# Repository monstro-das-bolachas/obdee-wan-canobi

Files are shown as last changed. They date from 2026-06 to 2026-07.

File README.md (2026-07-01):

# OBDee-Wan CANobi

> Open-hardware automotive bus interface for CAN FD, classic CAN, LIN, and K-line exploration.

OBDee-Wan CANobi is a Teensy 4.1 based vehicle-network tool for hackers, makers, reverse engineers, EV converters, and curious learners who want hardware they can inspect and understand.

It is designed as a practical bridge between a laptop and a vehicle or bench module: powerful enough for real CAN FD/LIN/K-line experiments, but documented as a teaching project rather than a black box.






## At a glance

| Area | Current R11 target |
| --- | --- |
| Host | Teensy 4.1 |
| CAN FD | 2 external CAN FD controller paths |
| Transceivers | Dual CAN FD transceivers |
| Other buses | LIN / K-line support path |
| Vehicle connection | OBD pigtail-friendly wiring, not a direct-plug dongle |
| Configuration | DIP-switch selectable routing options |
| CAD | KiCad hardware source and generated fabrication packages |
| Readiness | Bare-PCB prototype candidate for bench bring-up |

## What you can use it for

- CAN FD experimentation and learning
- Classic CAN diagnostics and reverse engineering
- LIN and K-line bench experiments
- EV conversion support tooling
- Custom diagnostic interface development
- Teaching automotive networks with inspectable hardware
- Bench testing ECUs, modules, sensors, and harness fragments

## Current status: R11 prototype manufacturing candidate

R11 may be ordered as a small bare-PCB prototype batch for bench bring-up.

It is not approved for direct vehicle testing yet.

### Active release package

`revisions/00_WORK_R11_TRUE_DUAL_CANFD/release/R11_PROTOTYPE_MANUFACTURING_CANDIDATE_20260630/`

### Manufacturer upload ZIP

`revisions/00_WORK_R11_TRUE_DUAL_CANFD/release/R11_PROTOTYPE_MANUFACTURING_CANDIDATE_20260630/package/JLCPCB_PCBWAY_UPLOAD_R11_MINIMAL_GERBERS_ONLY_20260630.zip`

SHA256:

`434dedf475bb3443f1ffa6384541426fcef9cf96a792c1744b9c1bb7ff68faa8`

### Verification summary

| Check | Result |
| --- | --- |
| KiCad CLI PCB DRC | 0 violations |
| KiCad schematic catalog ERC | 0 errors / 0 warnings |
| Footprint errors | 0 |
| Known residual | 1 GND zone-to-zone report at 1.0000 mm / 1.0000 mm |
| Gerber/drill export | Successful |
| GND continuity | Visually confirmed in KiCad after refill/highlight |
| BOM/CPL | PCB-derived BOM, grouped BOM, JLCPCB draft BOM/CPL included |
| Vehicle-use approval | Not yet; bench validation required first |

The remaining GND item is a reviewed KiCad zone-report artifact for prototype PCB ordering. It is not a blanket safety approval for vehicle connection.

## Safety first

Vehicle electrical systems can damage tools, modules, or the car if connected incorrectly. Treat every first assembly as experimental hardware.

Before connecting to a vehicle:

1. Inspect the bare PCB.
2. Check for rail shorts with a multimeter.
3. Assemble and test the power section first.
4. Power up from a current-limited bench supply.
5. Verify OBD/pigtail pin mapping manually.
6. Confirm DIP-switch defaults and intended routing.
7. Test CAN/LIN/K behavior on bench modules first.
8. Use fusing and current limiting for any later vehicle test.

## Repository map

| Path | Purpose |
| --- | --- |
| `README_START_HERE.txt` | Short navigation and safety guide |
| `CURRENT_STATUS.md` | Current revision status, ordering notes, and verification summary |
| `revisions/00_WORK_R11_TRUE_DUAL_CANFD/` | Active R11 prototype candidate source and release package |
| `revisions/00_WORK_R11_TRUE_DUAL_CANFD/docs/R11_BOM_FROM_PCB.md` | PCB-derived R11 BOM and procurement-review starting point |
| `revisions/00_WORK_R11_TRUE_DUAL_CANFD/docs/R11_PCB_DERIVED_NETLIST.md` | Pad/net evidence exported from the active PCB |
| `LOCAL_ARCHIVE_POINTERS.md` | Local-only pointers to R2-R10 evolution archives on this machine |
| GitHub releases / tags | Previous R10 and R9 snapshots; not duplicated in the latest working tree |
| `LICENSE` | Main hardware license: CERN-OHL-P-2.0 |
| `LICENSES/` | Full license texts and license split documentation |

## Recommended first order

For the first prototype batch, use conservative bare-board settings:

| Option | Recommendation |
| --- | --- |
| Quantity | 5 or smallest economical batch |
| Layers | 2 |
| Material | FR-4 |
| Thickness | 1.6 mm |
| Copper | 1 oz |
| Surface finish | Standard low-cost prototype finish is acceptable |
| Electrical test | Yes |
| Assembly | No; hand-assemble and validate first |

## Naming note

The project name is a small joke:

OBDee-Wan CANobi: an OBD/CAN interface that helps you feel disturbances in the bus.

## License

This project is open source and open hardware.

| Content | License |
| --- | --- |
| Hardware design files, KiCad sources, PCB/manufacturing files | CERN-OHL-P-2.0 |
| Firmware, scripts, and software | MIT |
| Documentation | CC-BY-4.0 |

You are free to study, modify, build, remix, and share this project. Attribution is required where applicable: please credit the original project and author when reusing or publishing derivative work.

See `LICENSES/README.md` for the full license split and SPDX identifiers.

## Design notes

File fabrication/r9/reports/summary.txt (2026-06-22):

R9 FAB_READY verification run: r9_fab_ready_20260622T095215Z
Board: /home/kali/teensy-41-can-lin-pcb/teensy-41-dual-canfd-lin-r9-final-candidate.kicad_pcb

=== KiCad version ===
10.0.3

=== PCB DRC ===
Found 0 violations
Found 0 unconnected items
Saved DRC Report to reports/r9_fab_ready_20260622T095215Z/drc.rpt
** Drc report for teensy-41-dual-canfd-lin-r9-final-candidate.kicad_pcb **
** Created on 2026-06-22T05:52:18 **
** Report includes: Errors, Warnings **

** Found 0 DRC violations **

** Found 0 unconnected pads **

** Found 0 Footprint errors **

** Ignored checks **
    - Footprint has no courtyard defined
    - Track endpoint not centered on via
    - Tuning profile track geometries
    - Footprint doesn't match symbol's footprint filters
    - Footprint component type doesn't match footprint pads

** End of Report **

=== SVG smoke export ===
Plotted to 'previews/r9_fab_ready_20260622T095215Z/teensy-41-dual-canfd-lin-r9-final-candidate-F_Cu.svg'.
Plotted to 'previews/r9_fab_ready_20260622T095215Z/teensy-41-dual-canfd-lin-r9-final-candidate-B_Cu.svg'.
Plotted to 'previews/r9_fab_ready_20260622T095215Z/teensy-41-dual-canfd-lin-r9-final-candidate-F_Silkscreen.svg'.
Plotted to 'previews/r9_fab_ready_20260622T095215Z/teensy-41-dual-canfd-lin-r9-final-candidate-B_Silkscreen.svg'.
Plotted to 'previews/r9_fab_ready_20260622T095215Z/teensy-41-dual-canfd-lin-r9-final-candidate-F_Fab.svg'.
Plotted to 'previews/r9_fab_ready_20260622T095215Z/teensy-41-dual-canfd-lin-r9-final-candidate-B_Fab.svg'.
Plotted to 'previews/r9_fab_ready_20260622T095215Z/teensy-41-dual-canfd-lin-r9-final-candidate-Edge_Cuts.svg'.
Done.

=== Gerber export ===
Plotted to 'gerbers/r9_fab_ready_20260622T095215Z/teensy-41-dual-canfd-lin-r9-final-candidate-F_Cu.gtl'.
Plotted to 'gerbers/r9_fab_ready_20260622T095215Z/teensy-41-dual-canfd-lin-r9-final-candidate-B_Cu.gbl'.
Plotted to 'gerbers/r9_fab_ready_20260622T095215Z/teensy-41-dual-canfd-lin-r9-final-candidate-F_Silkscreen.gto'.
Plotted to 'gerbers/r9_fab_ready_20260622T095215Z/teensy-41-dual-canfd-lin-r9-final-candidate-B_Silkscreen.gbo'.
Plotted to 'gerbers/r9_fab_ready_20260622T095215Z/teensy-41-dual-canfd-lin-r9-final-candidate-F_Mask.gts'.
Plotted to 'gerbers/r9_fab_ready_20260622T095215Z/teensy-41-dual-canfd-lin-r9-final-candidate-B_Mask.gbs'.
Plotted to 'gerbers/r9_fab_ready_20260622T095215Z/teensy-41-dual-canfd-lin-r9-final-candidate-Edge_Cuts.gm1'.

=== Drill export ===
Created file 'gerbers/r9_fab_ready_20260622T095215Z/teensy-41-dual-canfd-lin-r9-final-candidate.drl'
Done.

=== Gerber files ===
teensy-41-dual-canfd-lin-r9-final-candidate-B_Cu.gbl
teensy-41-dual-canfd-lin-r9-final-candidate-B_Mask.gbs
teensy-41-dual-canfd-lin-r9-final-candidate-B_Silkscreen.gbo
teensy-41-dual-canfd-lin-r9-final-candidate.drl
teensy-41-dual-canfd-lin-r9-final-candidate-Edge_Cuts.gm1
teensy-41-dual-canfd-lin-r9-final-candidate-F_Cu.gtl
teensy-41-dual-canfd-lin-r9-final-candidate-F_Mask.gts
teensy-41-dual-canfd-lin-r9-final-candidate-F_Silkscreen.gto
teensy-41-dual-canfd-lin-r9-final-candidate-job.gbrjob

=== Package status ===
FAB_READY
Package directory: /home/kali/teensy-41-can-lin-pcb/packages/r9_fab_ready_20260622T095215Z
Package zip: /home/kali/teensy-41-can-lin-pcb/FAB_READY_R9_teensy-41-dual-canfd-lin_20260622T095215Z.zip
f04ae2c23580a58f2644d54cbd61c455111c15dcdaf9954a5cab5cf20b73ea5e  FAB_READY_R9_teensy-41-dual-canfd-lin_20260622T095215Z.zip

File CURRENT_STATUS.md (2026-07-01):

# Current project status

Last checked/updated: 2026-06-30

## Executive summary

The active hardware revision is now **R11 true dual CAN FD + LIN/K prototype manufacturing candidate**.

R11 may be ordered as a small bare-PCB prototype batch for bench bring-up. It is **not approved for direct vehicle testing** until assembled boards pass continuity, power, pin-map, and fused OBD bench checks.

## Active R11 files

Active working revision folder:

- `revisions/00_WORK_R11_TRUE_DUAL_CANFD/`

Clean release package folder:

- `revisions/00_WORK_R11_TRUE_DUAL_CANFD/release/R11_PROTOTYPE_MANUFACTURING_CANDIDATE_20260630/`

Active KiCad source:

- `revisions/00_WORK_R11_TRUE_DUAL_CANFD/kicad/teensy-41-true-dual-canfd-lin-r11_JARVIS_ROUTED_CLEAN_V2_GND_STITCH.kicad_pcb`
- `revisions/00_WORK_R11_TRUE_DUAL_CANFD/kicad/teensy-41-true-dual-canfd-lin-r11_JARVIS_ROUTED_CLEAN_V2_GND_STITCH.kicad_pro`

JLCPCB / PCBWay upload ZIP:

- `revisions/00_WORK_R11_TRUE_DUAL_CANFD/release/R11_PROTOTYPE_MANUFACTURING_CANDIDATE_20260630/package/JLCPCB_PCBWAY_UPLOAD_R11_MINIMAL_GERBERS_ONLY_20260630.zip`

Full release ZIP:

- `revisions/00_WORK_R11_TRUE_DUAL_CANFD/release/R11_PROTOTYPE_MANUFACTURING_CANDIDATE_20260630/package/R11_PROTOTYPE_MANUFACTURING_CANDIDATE_20260630_FULL_RELEASE.zip`

## R11 verification

KiCad CLI DRC was run against the active board and the clean release-copy board.

Reports:

- `revisions/00_WORK_R11_TRUE_DUAL_CANFD/release/R11_PROTOTYPE_MANUFACTURING_CANDIDATE_20260630/reports/R11_PROTOTYPE_CANDIDATE_DRC.rpt`
- `revisions/00_WORK_R11_TRUE_DUAL_CANFD/release/R11_PROTOTYPE_MANUFACTURING_CANDIDATE_20260630/reports/R11_PROTOTYPE_CANDIDATE_CLEAN_RELEASE_COPY_DRC.rpt`

Result:

- DRC violations: 0
- Known residual: 1 GND F.Cu/B.Cu zone-to-zone unconnected report at 1.0000 mm / 1.0000 mm
- Footprint errors: 0
- Gerber/drill export: successful
- GND continuity: visually confirmed in KiCad after zone refill/highlight

The residual GND item is treated as a reviewed KiCad zone-report artifact for prototype PCB ordering, not as approval for vehicle use.

## R11 schematic/BOM completion

Added on 2026-07-01 from the active PCB:

- PCB-derived KiCad schematic catalog: `revisions/00_WORK_R11_TRUE_DUAL_CANFD/kicad/teensy-41-true-dual-canfd-lin-r11_JARVIS_ROUTED_CLEAN_V2_GND_STITCH.kicad_sch`
- KiCad ERC on the generated schematic catalog: 0 errors / 0 warnings
- KiCad schematic netlist export: `revisions/00_WORK_R11_TRUE_DUAL_CANFD/docs/R11_PCB_DERIVED_SCHEMATIC_NETLIST.xml`
- BOM: `revisions/00_WORK_R11_TRUE_DUAL_CANFD/docs/R11_BOM_FROM_PCB.md` and `.csv`
- Grouped BOM: `revisions/00_WORK_R11_TRUE_DUAL_CANFD/docs/R11_BOM_GROUPED_FROM_PCB.csv`
- JLCPCB draft BOM/CPL: `R11_JLCPCB_BOM_DRAFT.csv`, `R11_JLCPCB_CPL_DRAFT.csv`
- PCB-derived pad/net table: `R11_PCB_DERIVED_NETLIST.md`, `R11_PAD_NETS_FROM_PCB.csv`

Important limitation: this schematic is a PCB-derived catalog with footprint links and BOM/ERC proof, not yet a hand-reviewed functional wired schematic. The active PCB remains the layout authority; the pad/net table is the electrical evidence for review.

## R11 prototype ordering guidance

Order only a small bare-PCB batch first:

- 2 layers
- FR-4
- 1.6 mm
- 1 oz copper
- 5 pieces or smallest economical batch
- electrical test enabled
- no assembly for first order

Before vehicle testing:

1. Inspect bare PCBs.
2. Check GND continuity and rail shorts with a multimeter.
3. Assemble power section first.
4. Power from a current-limited bench supply.
5. Verify OBD/pigtail pin mapping with a multimeter.
6. Verify DIP switch safe/default positions.
7. Test CAN/LIN/K behavior on bench hardware before a fused OBD vehicle connection.

## Previous revision status

The latest working tree intentionally keeps only the active R11 prototype candidate under `revisions/`.

R10 and R9 remain available through GitHub history/releases/tags, but are no longer duplicated in the latest repository tree:

- R10: `NOT FOR FAB` after external review.
- R9: historical/reference material only; not true dual CAN FD.

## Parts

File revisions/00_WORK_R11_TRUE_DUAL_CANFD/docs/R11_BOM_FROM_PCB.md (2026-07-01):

# R11 BOM from active PCB

Source board: `../kicad/teensy-41-true-dual-canfd-lin-r11_JARVIS_ROUTED_CLEAN_V2_GND_STITCH.kicad_pcb`

Status: PCB-derived draft BOM. Suitable for procurement review, not automated assembly without MPN/LCSC completion.

Footprints/components: 59

| Qty | Designators | Value | Footprint | DNP | Notes |
|---:|---|---|---|---|---|
| 1 | `C1` | 100uF_50V_INPUT | `teensy-41-can-lin:CP_Radial_D8.0mm_P3.50mm` | NO | PCB-derived; verify exact MPN before assembly |
| 1 | `C2` | 100nF_50V_INPUT | `teensy-41-can-lin:C_0805_2012Metric_Pad1.18x1.45mm_HandSolder` | NO | PCB-derived; verify exact MPN before assembly |
| 1 | `C3` | 330uF_16V_OUTPUT_LOW_ESR | `teensy-41-can-lin:CP_Radial_D8.0mm_P3.50mm` | NO | PCB-derived; verify exact MPN before assembly |
| 1 | `C4` | 100nF_16V_OUTPUT | `teensy-41-can-lin:C_0805_2012Metric_Pad1.18x1.45mm_HandSolder` | NO | PCB-derived; verify exact MPN before assembly |
| 1 | `C5` | 100nF_CAN_A_VDD_LOCAL | `teensy-41-can-lin:C_0805_2012Metric_Pad1.18x1.45mm_HandSolder` | NO | PCB-derived; verify exact MPN before assembly |
| 1 | `C6` | 100nF_CAN_B_VDD_LOCAL | `teensy-41-can-lin:C_0805_2012Metric_Pad1.18x1.45mm_HandSolder` | NO | PCB-derived; verify exact MPN before assembly |
| 1 | `C7` | 100nF_LIN_VSUP_LOCAL | `teensy-41-can-lin:C_0805_2012Metric_Pad1.18x1.45mm_HandSolder` | NO | PCB-derived; verify exact MPN before assembly |
| 1 | `C8` | 22pF_Y1_OSC1 | `teensy-41-can-lin:C_0805_2012Metric_Pad1.18x1.45mm_HandSolder` | NO | PCB-derived; verify exact MPN before assembly |
| 1 | `C9` | 22pF_Y1_OSC2 | `teensy-41-can-lin:C_0805_2012Metric_Pad1.18x1.45mm_HandSolder` | NO | PCB-derived; verify exact MPN before assembly |
| 1 | `C10` | 22pF_Y2_OSC1 | `teensy-41-can-lin:C_0805_2012Metric_Pad1.18x1.45mm_HandSolder` | NO | PCB-derived; verify exact MPN before assembly |
| 1 | `C11` | 22pF_Y2_OSC2 | `teensy-41-can-lin:C_0805_2012Metric_Pad1.18x1.45mm_HandSolder` | NO | PCB-derived; verify exact MPN before assembly |
| 1 | `C12` | 100nF_U6_VDD_LOCAL | `teensy-41-can-lin:C_0805_2012Metric_Pad1.18x1.45mm_HandSolder` | NO | PCB-derived; verify exact MPN before assembly |
| 1 | `C13` | 100nF_U7_VDD_LOCAL | `teensy-41-can-lin:C_0805_2012Metric_Pad1.18x1.45mm_HandSolder` | NO | PCB-derived; verify exact MPN before assembly |
| 1 | `D1` | SMBJ24CA_TVS_12V | `teensy-41-can-lin:D_SMA` | NO | PCB-derived; verify exact MPN before assembly |
| 1 | `D2` | SS34_BUCK_SCHOTTKY | `teensy-41-can-lin:D_SMA` | NO | PCB-derived; verify exact MPN before assembly |
| 1 | `D3` | LIN_MASTER_PULLUP_DIODE_DNP | `teensy-41-can-lin:D_SMA` | YES | PCB-derived; verify exact MPN before assembly |
| 1 | `D4` | ESD_CAN_A_H_TVS_VERIFY | `teensy-41-can-lin:D_SMA` | NO | PCB-derived; verify exact MPN before assembly |
| 1 | `D5` | ESD_CAN_A_L_TVS_VERIFY | `teensy-41-can-lin:D_SMA` | NO | PCB-derived; verify exact MPN before assembly |
| 1 | `D6` | ESD_CAN_B_H_TVS_VERIFY | `teensy-41-can-lin:D_SMA` | NO | PCB-derived; verify exact MPN before assembly |
| 1 | `D7` | ESD_CAN_B_L_TVS_VERIFY | `teensy-41-can-lin:D_SMA` | NO | PCB-derived; verify exact MPN before assembly |
| 1 | `D8` | ESD_LIN_K_TVS_VERIFY | `teensy-41-can-lin:D_SMA` | NO | PCB-derived; verify exact MPN before assembly |
| 1 | `F1` | POLYFUSE_500mA | `teensy-41-can-lin:Fuse_1206_3216Metric` | NO | PCB-derived; verify exact MPN before assembly |
| 1 | `J1` | OBD2_PIGTAIL_16_WIRE_SOLDER_PADS | `teensy-41-can-lin:OBD2_PigtailPads_Manufacturing` | NO | PCB-derived; verify exact MPN before assembly |
| 1 | `J2` | AUX_HEADER | `teensy-41-can-lin:PinHeader_1x08_P2.54mm_Vertical` | NO | PCB-derived; verify exact MPN before assembly |
| 1 | `JP1` | LIN_MASTER_ENABLE_OPEN_0R_DNP | `teensy-41-can-lin:R_0805_2012Metric_Pad1.20x1.40mm_HandSolder` | YES | PCB-derived; verify exact MPN before assembly |
| 1 | `L1` | 33uH_3A_BUCK_INDUCTOR | `teensy-41-can-lin:L_Radial_D8.7mm_P5.00mm_Fastron_07HCP` | NO | PCB-derived; verify exact MPN before assembly |
| 4 | `MH1,MH2,MH3,MH4` | M3 | `teensy-41-can-lin:MountingHole_3.2mm_M3` | NO | PCB-derived; verify exact MPN before assembly |
| 1 | `R1` | 10k_LIN_RX_PULLUP | `teensy-41-can-lin:R_0805_2012Metric_Pad1.20x1.40mm_HandSolder` | NO | PCB-derived; verify exact MPN before assembly |
| 1 | `R11` | 100k_LIN_EN_PULLDOWN | `teensy-41-can-lin:R_0805_2012Metric_Pad1.20x1.40mm_HandSolder` | NO | PCB-derived; verify exact MPN before assembly |
| 1 | `R12` | 10k_CAN_A_STBY_PULLUP | `teensy-41-can-lin:R_0805_2012Metric_Pad1.20x1.40mm_HandSolder` | NO | PCB-derived; verify exact MPN before assembly |
| 1 | `R13` | 10k_CAN_B_STBY_PULLUP | `teensy-41-can-lin:R_0805_2012Metric_Pad1.20x1.40mm_HandSolder` | NO | PCB-derived; verify exact MPN before assembly |
| 1 | `R14` | 10k_CANFD_A_NCS_PULLUP | `teensy-41-can-lin:R_0805_2012Metric_Pad1.20x1.40mm_HandSolder` | NO | PCB-derived; verify exact MPN before assembly |
| 1 | `R15` | 10k_CANFD_B_NCS_PULLUP | `teensy-41-can-lin:R_0805_2012Metric_Pad1.20x1.40mm_HandSolder` | NO | PCB-derived; verify exact MPN before assembly |
| 1 | `R16` | 1k_LIN_MASTER_PULLUP_DNP | `teensy-41-can-lin:R_0805_2012Metric_Pad1.20x1.40mm_HandSolder` | YES | PCB-derived; verify exact MPN before assembly |
| 2 | `SR1,SR2` | CABLE_STRAIN_RELIEF | `teensy-41-can-lin:MountingHole_3.2mm_M3` | NO | PCB-derived; verify exact MPN before assembly |
| 1 | `SW1` | CAN_NORMAL_CROSS_DIP_8POS | `teensy-41-can-lin:SW_DIP_SPSTx08_Slide_9.78x22.5mm_W7.62mm_P2.54mm` | NO | PCB-derived; verify exact MPN before assembly |
| 1 | `SW2` | LIN_K_SOURCE_DIP_8POS_SELECT_ONE | `teensy-41-can-lin:SW_DIP_SPSTx08_Slide_9.78x22.5mm_W7.62mm_P2.54mm` | NO | PCB-derived; verify exact MPN before assembly |
| 1 | `TP1` | 12V | `teensy-41-can-lin:TestPoint_Pad_D1.5mm` | NO | PCB-derived; verify exact MPN before assembly |
| 1 | `TP2` | 5V | `teensy-41-can-lin:TestPoint_Pad_D1.5mm` | NO | PCB-derived; verify exact MPN before assembly |
| 1 | `TP3` | GND | `teensy-41-can-lin:TestPoint_Pad_D1.5mm` | NO | PCB-derived; verify exact MPN before assembly |
| 1 | `TP4` | CAN_A_H | `teensy-41-can-lin:TestPoint_Pad_D1.5mm` | NO | PCB-derived; verify exact MPN before assembly |
| 1 | `TP5` | CAN_A_L | `teensy-41-can-lin:TestPoint_Pad_D1.5mm` | NO | PCB-derived; verify exact MPN before assembly |
| 1 | `TP6` | CAN_B_H | `teensy-41-can-lin:TestPoint_Pad_D1.5mm` | NO | PCB-derived; verify exact MPN before assembly |
| 1 | `TP7` | CAN_B_L | `teensy-41-can-lin:TestPoint_Pad_D1.5mm` | NO | PCB-derived; verify exact MPN before assembly |
| 1 | `TP8` | LIN_BUS | `teensy-41-can-lin:TestPoint_Pad_D1.5mm` | NO | PCB-derived; verify exact MPN before assembly |
| 1 | `TP9` | AUX_LIN_K | `teensy-41-can-lin:TestPoint_Pad_D1.5mm` | NO | PCB-derived; verify exact MPN before assembly |
| 1 | `U1` | TEENSY_4.1_MAIN_HEADERS_PJRC_AUDITED | `teensy-41-can-lin:Teensy_4.1_MainHeaders_PJRC_Audited` | NO | PCB-derived; verify exact MPN before assembly |
| 1 | `U2` | MCP2562FD_CAN_A_3V3_IO | `teensy-41-can-lin:SOIC-8_3.9x4.9mm_P1.27mm` | NO | PCB-derived; verify exact MPN before assembly |
| 1 | `U3` | MCP2562FD_CAN_B_3V3_IO | `teensy-41-can-lin:SOIC-8_3.9x4.9mm_P1.27mm` | NO | PCB-derived; verify exact MPN before assembly |
| 1 | `U4` | TLIN1029DRQ1_LIN_3V3_LOGIC | `teensy-41-can-lin:SOIC-8_3.9x4.9mm_P1.27mm` | NO | PCB-derived; verify exact MPN before assembly |
| 1 | `U5` | LM2596S-5.0_BUCK | `teensy-41-can-lin:TO-263-5_TabPin3` | NO | PCB-derived; verify exact MPN before assembly |
| 1 | `U6` | MCP2518FD_A_SOIC14 | `teensy-41-can-lin:SOIC-14_3.9x8.7mm_P1.27mm` | NO | PCB-derived; verify exact MPN before assembly |
| 1 | `U7` | MCP2518FD_B_SOIC14 | `teensy-41-can-lin:SOIC-14_3.9x8.7mm_P1.27mm` | NO | PCB-derived; verify exact MPN before assembly |
| 2 | `Y1,Y2` | 40MHz_3225_VERIFY_CL | `teensy-41-can-lin:Crystal_SMD_3225-4Pin_3.2x2.5mm_HandSoldering` | NO | PCB-derived; verify exact MPN before assembly |

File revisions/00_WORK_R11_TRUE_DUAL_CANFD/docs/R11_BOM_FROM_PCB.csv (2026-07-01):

Reference | Value | Footprint | Layer | X_mm | Y_mm | Rotation_deg | DNP | Attributes
C1 | 100uF_50V_INPUT | teensy-41-can-lin:CP_Radial_D8.0mm_P3.50mm | F.Cu | 18.000 | 96.000 | 0.000 | NO | 1
C2 | 100nF_50V_INPUT | teensy-41-can-lin:C_0805_2012Metric_Pad1.18x1.45mm_HandSolder | F.Cu | 26.000 | 88.000 | 0.000 | NO | 2
C3 | 330uF_16V_OUTPUT_LOW_ESR | teensy-41-can-lin:CP_Radial_D8.0mm_P3.50mm | F.Cu | 72.000 | 96.000 | 0.000 | NO | 1
C4 | 100nF_16V_OUTPUT | teensy-41-can-lin:C_0805_2012Metric_Pad1.18x1.45mm_HandSolder | F.Cu | 72.000 | 84.000 | 0.000 | NO | 2
C5 | 100nF_CAN_A_VDD_LOCAL | teensy-41-can-lin:C_0805_2012Metric_Pad1.18x1.45mm_HandSolder | F.Cu | 86.000 | 18.000 | 180.000 | NO | 2
C6 | 100nF_CAN_B_VDD_LOCAL | teensy-41-can-lin:C_0805_2012Metric_Pad1.18x1.45mm_HandSolder | F.Cu | 92.000 | 39.000 | 0.000 | NO | 2
C7 | 100nF_LIN_VSUP_LOCAL | teensy-41-can-lin:C_0805_2012Metric_Pad1.18x1.45mm_HandSolder | F.Cu | 82.000 | 64.000 | 0.000 | NO | 2
C8 | 22pF_Y1_OSC1 | teensy-41-can-lin:C_0805_2012Metric_Pad1.18x1.45mm_HandSolder | F.Cu | 214.000 | 24.038 | 90.000 | NO | 2
C9 | 22pF_Y1_OSC2 | teensy-41-can-lin:C_0805_2012Metric_Pad1.18x1.45mm_HandSolder | F.Cu | 205.963 | 18.000 | 0.000 | NO | 2
C10 | 22pF_Y2_OSC1 | teensy-41-can-lin:C_0805_2012Metric_Pad1.18x1.45mm_HandSolder | F.Cu | 206.000 | 56.000 | 90.000 | NO | 2
C11 | 22pF_Y2_OSC2 | teensy-41-can-lin:C_0805_2012Metric_Pad1.18x1.45mm_HandSolder | F.Cu | 205.000 | 69.463 | -90.000 | NO | 2
C12 | 100nF_U6_VDD_LOCAL | teensy-41-can-lin:C_0805_2012Metric_Pad1.18x1.45mm_HandSolder | F.Cu | 184.000 | 24.000 | 180.000 | NO | 2
C13 | 100nF_U7_VDD_LOCAL | teensy-41-can-lin:C_0805_2012Metric_Pad1.18x1.45mm_HandSolder | F.Cu | 181.000 | 62.000 | 0.000 | NO | 2
D1 | SMBJ24CA_TVS_12V | teensy-41-can-lin:D_SMA | F.Cu | 24.000 | 80.000 | 0.000 | NO | 2
D2 | SS34_BUCK_SCHOTTKY | teensy-41-can-lin:D_SMA | F.Cu | 56.000 | 98.000 | 0.000 | NO | 2
D3 | LIN_MASTER_PULLUP_DIODE_DNP | teensy-41-can-lin:D_SMA | F.Cu | 200.000 | 82.000 | 0.000 | YES | 2
D4 | ESD_CAN_A_H_TVS_VERIFY | teensy-41-can-lin:D_SMA | F.Cu | 176.000 | 92.000 | 0.000 | NO | 2
D5 | ESD_CAN_A_L_TVS_VERIFY | teensy-41-can-lin:D_SMA | F.Cu | 188.000 | 92.000 | 0.000 | NO | 2
D6 | ESD_CAN_B_H_TVS_VERIFY | teensy-41-can-lin:D_SMA | F.Cu | 200.000 | 92.000 | 0.000 | NO | 2
D7 | ESD_CAN_B_L_TVS_VERIFY | teensy-41-can-lin:D_SMA | F.Cu | 212.000 | 92.000 | 0.000 | NO | 2
D8 | ESD_LIN_K_TVS_VERIFY | teensy-41-can-lin:D_SMA | F.Cu | 176.000 | 100.000 | 0.000 | NO | 2
F1 | POLYFUSE_500mA | teensy-41-can-lin:Fuse_1206_3216Metric | F.Cu | 30.000 | 72.000 | 0.000 | NO | 2
J1 | OBD2_PIGTAIL_16_WIRE_SOLDER_PADS | teensy-41-can-lin:OBD2_PigtailPads_Manufacturing | F.Cu | 0.000 | 0.000 | 0.000 | NO | 0
J2 | AUX_HEADER | teensy-41-can-lin:PinHeader_1x08_P2.54mm_Vertical | F.Cu | 158.000 | 62.000 | 0.000 | NO | 1
JP1 | LIN_MASTER_ENABLE_OPEN_0R_DNP | teensy-41-can-lin:R_0805_2012Metric_Pad1.20x1.40mm_HandSolder | F.Cu | 208.000 | 82.000 | 0.000 | YES | 2
L1 | 33uH_3A_BUCK_INDUCTOR | teensy-41-can-lin:L_Radial_D8.7mm_P5.00mm_Fastron_07HCP | F.Cu | 58.000 | 88.000 | 0.000 | NO | 1
MH1 | M3 | teensy-41-can-lin:MountingHole_3.2mm_M3 | F.Cu | 6.000 | 6.000 | 0.000 | NO | 12
MH2 | M3 | teensy-41-can-lin:MountingHole_3.2mm_M3 | F.Cu | 224.000 | 6.000 | 0.000 | NO | 12
MH3 | M3 | teensy-41-can-lin:MountingHole_3.2mm_M3 | F.Cu | 6.000 | 99.000 | 0.000 | NO | 12
MH4 | M3 | teensy-41-can-lin:MountingHole_3.2mm_M3 | F.Cu | 224.000 | 109.000 | 0.000 | NO | 12
R1 | 10k_LIN_RX_PULLUP | teensy-41-can-lin:R_0805_2012Metric_Pad1.20x1.40mm_HandSolder | F.Cu | 86.000 | 58.000 | 0.000 | NO | 2
R11 | 100k_LIN_EN_PULLDOWN | teensy-41-can-lin:R_0805_2012Metric_Pad1.20x1.40mm_HandSolder | F.Cu | 184.000 | 82.000 | 0.000 | NO | 2
R12 | 10k_CAN_A_STBY_PULLUP | teensy-41-can-lin:R_0805_2012Metric_Pad1.20x1.40mm_HandSolder | F.Cu | 184.000 | 12.000 | 0.000 | NO | 2
R13 | 10k_CAN_B_STBY_PULLUP | teensy-41-can-lin:R_0805_2012Metric_Pad1.20x1.40mm_HandSolder | F.Cu | 184.000 | 42.000 | 0.000 | NO | 2
R14 | 10k_CANFD_A_NCS_PULLUP | teensy-41-can-lin:R_0805_2012Metric_Pad1.20x1.40mm_HandSolder | F.Cu | 168.000 | 12.000 | 0.000 | NO | 2
R15 | 10k_CANFD_B_NCS_PULLUP | teensy-41-can-lin:R_0805_2012Metric_Pad1.20x1.40mm_HandSolder | F.Cu | 168.000 | 42.000 | 0.000 | NO | 2
R16 | 1k_LIN_MASTER_PULLUP_DNP | teensy-41-can-lin:R_0805_2012Metric_Pad1.20x1.40mm_HandSolder | F.Cu | 216.000 | 82.000 | 0.000 | YES | 2
SR1 | CABLE_STRAIN_RELIEF | teensy-41-can-lin:MountingHole_3.2mm_M3 | F.Cu | 10.000 | 60.000 | 0.000 | NO | 12
SR2 | CABLE_STRAIN_RELIEF | teensy-41-can-lin:MountingHole_3.2mm_M3 | F.Cu | 22.000 | 66.000 | 0.000 | NO | 12
SW1 | CAN_NORMAL_CROSS_DIP_8POS | teensy-41-can-lin:SW_DIP_SPSTx08_Slide_9.78x22.5mm_W7.62mm_P2.54mm | F.Cu | 55.000 | 13.000 | 0.000 | NO | 1
SW2 | LIN_K_SOURCE_DIP_8POS_SELECT_ONE | teensy-41-can-lin:SW_DIP_SPSTx08_Slide_9.78x22.5mm_W7.62mm_P2.54mm | F.Cu | 55.000 | 52.000 | 0.000 | NO | 1
TP1 | 12V | teensy-41-can-lin:TestPoint_Pad_D1.5mm | F.Cu | 34.000 | 60.000 | 0.000 | NO | 12
TP2 | 5V | teensy-41-can-lin:TestPoint_Pad_D1.5mm | F.Cu | 44.000 | 60.000 | 0.000 | NO | 12
TP3 | GND | teensy-41-can-lin:TestPoint_Pad_D1.5mm | F.Cu | 24.000 | 60.000 | 0.000 | NO | 12
TP4 | CAN_A_H | teensy-41-can-lin:TestPoint_Pad_D1.5mm | F.Cu | 111.000 | 18.000 | 0.000 | NO | 12
TP5 | CAN_A_L | teensy-41-can-lin:TestPoint_Pad_D1.5mm | F.Cu | 111.000 | 24.000 | 0.000 | NO | 12
TP6 | CAN_B_H | teensy-41-can-lin:TestPoint_Pad_D1.5mm | F.Cu | 111.000 | 39.000 | 0.000 | NO | 12
TP7 | CAN_B_L | teensy-41-can-lin:TestPoint_Pad_D1.5mm | F.Cu | 111.000 | 45.000 | 0.000 | NO | 12
TP8 | LIN_BUS | teensy-41-can-lin:TestPoint_Pad_D1.5mm | F.Cu | 111.000 | 64.000 | 0.000 | NO | 12
TP9 | AUX_LIN_K | teensy-41-can-lin:TestPoint_Pad_D1.5mm | F.Cu | 158.000 | 88.000 | 0.000 | NO | 12
U1 | TEENSY_4.1_MAIN_HEADERS_PJRC_AUDITED | teensy-41-can-lin:Teensy_4.1_MainHeaders_PJRC_Audited | F.Cu | 154.240 | -88.420 | -90.000 | NO | 0
U2 | MCP2562FD_CAN_A_3V3_IO | teensy-41-can-lin:SOIC-8_3.9x4.9mm_P1.27mm | B.Cu | 131.025 | 34.095 | 90.000 | NO | 2
U3 | MCP2562FD_CAN_B_3V3_IO | teensy-41-can-lin:SOIC-8_3.9x4.9mm_P1.27mm | B.Cu | 131.525 | 57.095 | 180.000 | NO | 2
U4 | TLIN1029DRQ1_LIN_3V3_LOGIC | teensy-41-can-lin:SOIC-8_3.9x4.9mm_P1.27mm | B.Cu | 131.525 | 82.095 | -90.000 | NO | 2
U5 | LM2596S-5.0_BUCK | teensy-41-can-lin:TO-263-5_TabPin3 | F.Cu | 42.000 | 88.000 | 0.000 | NO | 2
U6 | MCP2518FD_A_SOIC14 | teensy-41-can-lin:SOIC-14_3.9x8.7mm_P1.27mm | B.Cu | 192.000 | 24.000 | 180.000 | NO | 2
U7 | MCP2518FD_B_SOIC14 | teensy-41-can-lin:SOIC-14_3.9x8.7mm_P1.27mm | B.Cu | 192.000 | 62.000 | 180.000 | NO | 2
Y1 | 40MHz_3225_VERIFY_CL | teensy-41-can-lin:Crystal_SMD_3225-4Pin_3.2x2.5mm_HandSoldering | F.Cu | 206.000 | 24.000 | 90.000 | NO | 2
Y2 | 40MHz_3225_VERIFY_CL | teensy-41-can-lin:Crystal_SMD_3225-4Pin_3.2x2.5mm_HandSoldering | F.Cu | 206.000 | 62.000 | 90.000 | NO | 2

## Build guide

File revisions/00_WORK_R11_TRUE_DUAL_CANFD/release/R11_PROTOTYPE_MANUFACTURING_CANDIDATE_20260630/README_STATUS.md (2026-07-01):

# R11 status

Status: PROTOTYPE_MANUFACTURING_CANDIDATE.

This revision is suitable for ordering a small bare-PCB prototype batch for bench bring-up. It is not approved for direct vehicle testing yet.

Active board:
`kicad/teensy-41-true-dual-canfd-lin-r11_JARVIS_ROUTED_CLEAN_V2_GND_STITCH.kicad_pcb`

Manufacturing upload ZIP:
`package/JLCPCB_PCBWAY_UPLOAD_R11_MINIMAL_GERBERS_ONLY_20260630.zip`

Full release archive:
`package/R11_PROTOTYPE_MANUFACTURING_CANDIDATE_20260630_FULL_RELEASE.zip`

Verification:
- KiCad CLI DRC: 0 DRC violations.
- Known residual: 1 GND zone-to-zone unconnected report at 1.0000 mm / 1.0000 mm.
- GND continuity: visually confirmed in KiCad by user after zone refill/highlight.
- Gerber/drill export: completed by KiCad CLI.

Schematic/BOM update:
- PCB-derived KiCad schematic catalog is included in `kicad/`.
- KiCad ERC on that schematic catalog: 0 errors / 0 warnings.
- BOM, grouped BOM, JLCPCB draft BOM/CPL, KiCad BOM XML, and PCB-derived pad/net exports are included in `docs/`.
- Limitation: schematic is PCB-derived for catalog/BOM/ERC; it is not a hand-reviewed functional wired schematic yet.

Do not use on a vehicle until:
1. Bare PCB continuity is checked.
2. Power rails are checked for shorts.
3. Board is powered from current-limited bench supply.
4. OBD/pigtail pin mapping is verified with a multimeter.
5. DIP switch default-safe positions are documented and confirmed.
6. CAN/LIN/K-line behavior is tested on bench hardware first.

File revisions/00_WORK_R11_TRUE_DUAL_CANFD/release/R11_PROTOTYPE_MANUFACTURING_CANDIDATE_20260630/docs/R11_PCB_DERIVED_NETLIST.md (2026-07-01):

# R11 PCB-derived pad/net table

Source: active R11 PCB. This is the authoritative net evidence until the functional schematic is hand-reviewed.

## C1 - 100uF_50V_INPUT
Footprint: `teensy-41-can-lin:CP_Radial_D8.0mm_P3.50mm`

| Pad | Name | Net |
|---|---|---|
| 1 | 1 | `+12V_PROTECTED` |
| 2 | 2 | `GND` |

## C2 - 100nF_50V_INPUT
Footprint: `teensy-41-can-lin:C_0805_2012Metric_Pad1.18x1.45mm_HandSolder`

| Pad | Name | Net |
|---|---|---|
| 1 | 1 | `+12V_PROTECTED` |
| 2 | 2 | `GND` |

## C3 - 330uF_16V_OUTPUT_LOW_ESR
Footprint: `teensy-41-can-lin:CP_Radial_D8.0mm_P3.50mm`

| Pad | Name | Net |
|---|---|---|
| 1 | 1 | `+5V_REGULATED` |
| 2 | 2 | `GND` |

## C4 - 100nF_16V_OUTPUT
Footprint: `teensy-41-can-lin:C_0805_2012Metric_Pad1.18x1.45mm_HandSolder`

| Pad | Name | Net |
|---|---|---|
| 1 | 1 | `+5V_REGULATED` |
| 2 | 2 | `GND` |

## C5 - 100nF_CAN_A_VDD_LOCAL
Footprint: `teensy-41-can-lin:C_0805_2012Metric_Pad1.18x1.45mm_HandSolder`

| Pad | Name | Net |
|---|---|---|
| 1 | 1 | `+5V_REGULATED` |
| 2 | 2 | `GND` |

## C6 - 100nF_CAN_B_VDD_LOCAL
Footprint: `teensy-41-can-lin:C_0805_2012Metric_Pad1.18x1.45mm_HandSolder`

| Pad | Name | Net |
|---|---|---|
| 1 | 1 | `+5V_REGULATED` |
| 2 | 2 | `GND` |

## C7 - 100nF_LIN_VSUP_LOCAL
Footprint: `teensy-41-can-lin:C_0805_2012Metric_Pad1.18x1.45mm_HandSolder`

| Pad | Name | Net |
|---|---|---|
| 1 | 1 | `+12V_PROTECTED` |
| 2 | 2 | `GND` |

## C8 - 22pF_Y1_OSC1
Footprint: `teensy-41-can-lin:C_0805_2012Metric_Pad1.18x1.45mm_HandSolder`

| Pad | Name | Net |
|---|---|---|
| 1 | 1 | `CANFD_A_OSC1` |
| 2 | 2 | `GND` |

## C9 - 22pF_Y1_OSC2
Footprint: `teensy-41-can-lin:C_0805_2012Metric_Pad1.18x1.45mm_HandSolder`

| Pad | Name | Net |
|---|---|---|
| 1 | 1 | `CANFD_A_OSC2` |
| 2 | 2 | `GND` |

## C10 - 22pF_Y2_OSC1
Footprint: `teensy-41-can-lin:C_0805_2012Metric_Pad1.18x1.45mm_HandSolder`

| Pad | Name | Net |
|---|---|---|
| 1 | 1 | `CANFD_B_OSC1` |
| 2 | 2 | `GND` |

## C11 - 22pF_Y2_OSC2
Footprint: `teensy-41-can-lin:C_0805_2012Metric_Pad1.18x1.45mm_HandSolder`

| Pad | Name | Net |
|---|---|---|
| 1 | 1 | `CANFD_B_OSC2` |
| 2 | 2 | `GND` |

## C12 - 100nF_U6_VDD_LOCAL
Footprint: `teensy-41-can-lin:C_0805_2012Metric_Pad1.18x1.45mm_HandSolder`

| Pad | Name | Net |
|---|---|---|
| 1 | 1 | `+3V3` |
| 2 | 2 | `GND` |

## C13 - 100nF_U7_VDD_LOCAL
Footprint: `teensy-41-can-lin:C_0805_2012Metric_Pad1.18x1.45mm_HandSolder`

| Pad | Name | Net |
|---|---|---|
| 1 | 1 | `+3V3` |
| 2 | 2 | `GND` |

## D1 - SMBJ24CA_TVS_12V
Footprint: `teensy-41-can-lin:D_SMA`

| Pad | Name | Net |
|---|---|---|
| 1 | 1 | `+12V_PROTECTED` |
| 2 | 2 | `GND` |

## D2 - SS34_BUCK_SCHOTTKY
Footprint: `teensy-41-can-lin:D_SMA`

| Pad | Name | Net |
|---|---|---|
| 1 | 1 | `BUCK_SW` |
| 2 | 2 | `GND` |

## D3 - LIN_MASTER_PULLUP_DIODE_DNP
Footprint: `teensy-41-can-lin:D_SMA`

| Pad | Name | Net |
|---|---|---|
| 1 | 1 | `+12V_PROTECTED` |
| 2 | 2 | `LIN_MASTER_DIODE_OUT` |

## D4 - ESD_CAN_A_H_TVS_VERIFY
Footprint: `teensy-41-can-lin:D_SMA`

| Pad | Name | Net |
|---|---|---|
| 1 | 1 | `CAN_A_H` |
| 2 | 2 | `GND` |

## D5 - ESD_CAN_A_L_TVS_VERIFY
Footprint: `teensy-41-can-lin:D_SMA`

| Pad | Name | Net |
|---|---|---|
| 1 | 1 | `CAN_A_L` |
| 2 | 2 | `GND` |

## D6 - ESD_CAN_B_H_TVS_VERIFY
Footprint: `teensy-41-can-lin:D_SMA`

| Pad | Name | Net |
|---|---|---|
| 1 | 1 | `CAN_B_H` |
| 2 | 2 | `GND` |

## D7 - ESD_CAN_B_L_TVS_VERIFY
Footprint: `teensy-41-can-lin:D_SMA`

| Pad | Name | Net |
|---|---|---|
| 1 | 1 | `CAN_B_L` |
| 2 | 2 | `GND` |

## D8 - ESD_LIN_K_TVS_VERIFY
Footprint: `teensy-41-can-lin:D_SMA`

| Pad | Name | Net |
|---|---|---|
| 1 | 1 | `LIN_BUS` |
| 2 | 2 | `GND` |

## F1 - POLYFUSE_500mA
Footprint: `teensy-41-can-lin:Fuse_1206_3216Metric`

| Pad | Name | Net |
|---|---|---|
| 1 | 1 | `+12V_OBD` |
| 2 | 2 | `+12V_PROTECTED` |

## J1 - OBD2_PIGTAIL_16_WIRE_SOLDER_PADS
Footprint: `teensy-41-can-lin:OBD2_PigtailPads_Manufacturing`

| Pad | Name | Net |
|---|---|---|
| 1 | 1 | `OBD1_SINGLE_WIRE_CANDIDATE` |
| 2 | 2 | `OBD2_SPARE_PWM_J1850_CANDIDATE` |
| 3 | 3 | `OBD3_CAN_B_PAIR_A_CANDIDATE` |
| 4 | 4 | `GND` |
| 5 | 5 | `GND` |
| 6 | 6 | `OBD6_CAN_A_PAIR_A` |
| 7 | 7 | `OBD7_SINGLE_WIRE_CANDIDATE` |
| 8 | 8 | `OBD8_SINGLE_WIRE_CANDIDATE` |
| 9 | 9 | `OBD9_SINGLE_WIRE_CANDIDATE` |
| 10 | 10 | `OBD10_SPARE_PWM_J1850_CANDIDATE` |
| 11 | 11 | `OBD11_CAN_B_PAIR_B_CANDIDATE` |
| 12 | 12 | `OBD12_SINGLE_WIRE_CANDIDATE` |
| 13 | 13 | `OBD13_SINGLE_WIRE_CANDIDATE` |
| 14 | 14 | `OBD14_CAN_A_PAIR_B` |
| 15 | 15 | `OBD15_SINGLE_WIRE_CANDIDATE` |
| 16 | 16 | `+12V_OBD` |

## J2 - AUX_HEADER
Footprint: `teensy-41-can-lin:PinHeader_1x08_P2.54mm_Vertical`

| Pad | Name | Net |
|---|---|---|
| 1 | 1 | `CAN_B_H` |
| 2 | 2 | `CAN_B_L` |
| 3 | 3 | `AUX_LIN_K_IO` |
| 4 | 4 | `GND` |
| 5 | 5 | `+5V_REGULATED` |
| 6 | 6 | `+12V_PROTECTED` |
| 7 | 7 | `CAN_A_H` |
| 8 | 8 | `CAN_A_L` |

## JP1 - LIN_MASTER_ENABLE_OPEN_0R_DNP
Footprint: `teensy-41-can-lin:R_0805_2012Metric_Pad1.20x1.40mm_HandSolder`

| Pad | Name | Net |
|---|---|---|
| 1 | 1 | `LIN_MASTER_DIODE_OUT` |
| 2 | 2 | `LIN_MASTER_ENABLE` |

## L1 - 33uH_3A_BUCK_INDUCTOR
Footprint: `teensy-41-can-lin:L_Radial_D8.7mm_P5.00mm_Fastron_07HCP`

| Pad | Name | Net |
|---|---|---|
| 1 | 1 | `BUCK_SW` |
| 2 | 2 | `+5V_REGULATED` |

## MH1 - M3
Footprint: `teensy-41-can-lin:MountingHole_3.2mm_M3`

| Pad | Name | Net |
|---|---|---|
|  |  | `` |

## MH2 - M3
Footprint: `teensy-41-can-lin:MountingHole_3.2mm_M3`

| Pad | Name | Net |
|---|---|---|
|  |  | `` |

## MH3 - M3
Footprint: `teensy-41-can-lin:MountingHole_3.2mm_M3`

| Pad | Name | Net |
|---|---|---|
|  |  | `` |

## MH4 - M3
Footprint: `teensy-41-can-lin:MountingHole_3.2mm_M3`

| Pad | Name | Net |
|---|---|---|
|  |  | `` |

## R1 - 10k_LIN_RX_PULLUP
Footprint: `teensy-41-can-lin:R_0805_2012Metric_Pad1.20x1.40mm_HandSolder`

| Pad | Name | Net |
|---|---|---|
| 1 | 1 | `LIN_RX` |
| 2 | 2 | `+3V3` |

## R11 - 100k_LIN_EN_PULLDOWN
Footprint: `teensy-41-can-lin:R_0805_2012Metric_Pad1.20x1.40mm_HandSolder`

| Pad | Name | Net |
|---|---|---|
| 1 | 1 | `LIN_EN` |
| 2 | 2 | `GND` |

## R12 - 10k_CAN_A_STBY_PULLUP
Footprint: `teensy-41-can-lin:R_0805_2012Metric_Pad1.20x1.40mm_HandSolder`

| Pad | Name | Net |
|---|---|---|
| 1 | 1 | `CANFD_A_XSTBY` |
| 2 | 2 | `+3V3` |

## R13 - 10k_CAN_B_STBY_PULLUP
Footprint: `teensy-41-can-lin:R_0805_2012Metric_Pad1.20x1.40mm_HandSolder`

| Pad | Name | Net |
|---|---|---|
| 1 | 1 | `CANFD_B_XSTBY` |
| 2 | 2 | `+3V3` |

## R14 - 10k_CANFD_A_NCS_PULLUP
Footprint: `teensy-41-can-lin:R_0805_2012Metric_Pad1.20x1.40mm_HandSolder`

| Pad | Name | Net |
|---|---|---|
| 1 | 1 | `CANFD_A_NCS` |
| 2 | 2 | `+3V3` |

## R15 - 10k_CANFD_B_NCS_PULLUP
Footprint: `teensy-41-can-lin:R_0805_2012Metric_Pad1.20x1.40mm_HandSolder`

| Pad | Name | Net |
|---|---|---|
| 1 | 1 | `CANFD_B_NCS` |
| 2 | 2 | `+3V3` |

## R16 - 1k_LIN_MASTER_PULLUP_DNP
Footprint: `teensy-41-can-lin:R_0805_2012Metric_Pad1.20x1.40mm_HandSolder`

| Pad | Name | Net |
|---|---|---|
| 1 | 1 | `LIN_MASTER_ENABLE` |
| 2 | 2 | `LIN_BUS` |

## SR1 - CABLE_STRAIN_RELIEF
Footprint: `teensy-41-can-lin:MountingHole_3.2mm_M3`

| Pad | Name | Net |
|---|---|---|
|  |  | `` |

## SR2 - CABLE_STRAIN_RELIEF
Footprint: `teensy-41-can-lin:MountingHole_3.2mm_M3`

| Pad | Name | Net |
|---|---|---|
|  |  | `` |

## SW1 - CAN_NORMAL_CROSS_DIP_8POS
Footprint: `teensy-41-can-lin:SW_DIP_SPSTx08_Slide_9.78x22.5mm_W7.62mm_P2.54mm`

| Pad | Name | Net |
|---|---|---|
| 1 | 1 | `OBD6_CAN_A_PAIR_A` |
| 2 | 2 | `OBD14_CAN_A_PAIR_B` |
| 3 | 3 | `OBD6_CAN_A_PAIR_A` |
| 4 | 4 | `OBD14_CAN_A_PAIR_B` |
| 5 | 5 | `OBD3_CAN_B_PAIR_A_CANDIDATE` |
| 6 | 6 | `OBD11_CAN_B_PAIR_B_CANDIDATE` |
| 7 | 7 | `OBD3_CAN_B_PAIR_A_CANDIDATE` |
| 8 | 8 | `OBD11_CAN_B_PAIR_B_CANDIDATE` |
| 9 | 9 | `CAN_B_H` |
| 10 | 10 | `CAN_B_L` |
| 11 | 11 | `CAN_B_L` |
| 12 | 12 | `CAN_B_H` |
| 13 | 13 | `CAN_A_H` |
| 14 | 14 | `CAN_A_L` |
| 15 | 15 | `CAN_A_L` |
| 16 | 16 | `CAN_A_H` |

## SW2 - LIN_K_SOURCE_DIP_8POS_SELECT_ONE
Footprint: `teensy-41-can-lin:SW_DIP_SPSTx08_Slide_9.78x22.5mm_W7.62mm_P2.54mm`

| Pad | Name | Net |
|---|---|---|
| 1 | 1 | `OBD7_SINGLE_WIRE_CANDIDATE` |
| 2 | 2 | `OBD15_SINGLE_WIRE_CANDIDATE` |
| 3 | 3 | `OBD1_SINGLE_WIRE_CANDIDATE` |
| 4 | 4 | `OBD8_SINGLE_WIRE_CANDIDATE` |
| 5 | 5 | `OBD9_SINGLE_WIRE_CANDIDATE` |
| 6 | 6 | `OBD12_SINGLE_WIRE_CANDIDATE` |
| 7 | 7 | `OBD13_SINGLE_WIRE_CANDIDATE` |
| 8 | 8 | `AUX_LIN_K_IO` |
| 9 | 9 | `LIN_BUS` |
| 10 | 10 | `LIN_BUS` |
| 11 | 11 | `LIN_BUS` |
| 12 | 12 | `LIN_BUS` |
| 13 | 13 | `LIN_BUS` |
| 14 | 14 | `LIN_BUS` |
| 15 | 15 | `LIN_BUS` |
| 16 | 16 | `LIN_BUS` |

## TP1 - 12V
Footprint: `teensy-41-can-lin:TestPoint_Pad_D1.5mm`

| Pad | Name | Net |
|---|---|---|
| 1 | 1 | `+12V_OBD` |

## TP2 - 5V
Footprint: `teensy-41-can-lin:TestPoint_Pad_D1.5mm`

| Pad | Name | Net |
|---|---|---|
| 1 | 1 | `+5V_REGULATED` |

## TP3 - GND
Footprint: `teensy-41-can-lin:TestPoint_Pad_D1.5mm`

| Pad | Name | Net |
|---|---|---|
| 1 | 1 | `GND` |

## TP4 - CAN_A_H
Footprint: `teensy-41-can-lin:TestPoint_Pad_D1.5mm`

| Pad | Name | Net |
|---|---|---|
| 1 | 1 | `CAN_A_H` |

## TP5 - CAN_A_L
Footprint: `teensy-41-can-lin:TestPoint_Pad_D1.5mm`

| Pad | Name | Net |
|---|---|---|
| 1 | 1 | `CAN_A_L` |

## TP6 - CAN_B_H
Footprint: `teensy-41-can-lin:TestPoint_Pad_D1.5mm`

| Pad | Name | Net |
|---|---|---|
| 1 | 1 | `CAN_B_H` |

## TP7 - CAN_B_L
Footprint: `teensy-41-can-lin:TestPoint_Pad_D1.5mm`

| Pad | Name | Net |
|---|---|---|
| 1 | 1 | `CAN_B_L` |

## TP8 - LIN_BUS
Footprint: `teensy-41-can-lin:TestPoint_Pad_D1.5mm`

| Pad | Name | Net |
|---|---|---|
| 1 | 1 | `LIN_BUS` |

## TP9 - AUX_LIN_K
Footprint: `teensy-41-can-lin:TestPoint_Pad_D1.5mm`

| Pad | Name | Net |
|---|---|---|
| 1 | 1 | `AUX_LIN_K_IO` |

## U1 - TEENSY_4.1_MAIN_HEADERS_PJRC_AUDITED
Footprint: `teensy-41-can-lin:Teensy_4.1_MainHeaders_PJRC_Audited`

| Pad | Name | Net |
|---|---|---|
| 0 | 0 | `` |
| 1 | 1 | `` |
| 2 | 2 | `CANFD_A_INT` |
| 3 | 3 | `CANFD_B_INT` |
| 3V3_B | 3V3_B | `+3V3` |
| 4 | 4 | `` |
| 5 | 5 | `` |
| 6 | 6 | `LIN_EN` |
| 7 | 7 | `LIN_RX` |
| 8 | 8 | `LIN_TX` |
| 9 | 9 | `CANFD_B_NCS` |
| 10 | 10 | `CANFD_A_NCS` |
| 11 | 11 | `CANFD_SPI_SDI_MOSI` |
| 12 | 12 | `CANFD_SPI_SDO_MISO` |
| 13 | 13 | `CANFD_SPI_SCK` |
| 14 | 14 | `` |
| 15 | 15 | `` |
| 16 | 16 | `` |
| 17 | 17 | `` |
| 18 | 18 | `` |
| 19 | 19 | `` |
| 20 | 20 | `` |
| 21 | 21 | `` |
| 22 | 22 | `` |
| 23 | 23 | `` |
| 24 | 24 | `` |
| 25 | 25 | `` |
| 26 | 26 | `` |
| 27 | 27 | `` |
| 28 | 28 | `` |
| 29 | 29 | `` |
| 30 | 30 | `` |
| 31 | 31 | `` |
| 32 | 32 | `` |
| 33 | 33 | `` |
| 34 | 34 | `` |
| 35 | 35 | `` |
| 36 | 36 | `` |
| 37 | 37 | `` |
| 38 | 38 | `` |
| 39 | 39 | `` |
| 40 | 40 | `` |
| 41 | 41 | `` |
| GND_B1 | GND_B1 | `GND` |
| GND_T1 | GND_T1 | `GND` |
| GND_T2 | GND_T2 | `GND` |
| VIN | VIN | `+5V_REGULATED` |

## U2 - MCP2562FD_CAN_A_3V3_IO
Footprint: `teensy-41-can-lin:SOIC-8_3.9x4.9mm_P1.27mm`

| Pad | Name | Net |
|---|---|---|
| 1 | 1 | `CANFD_A_TXCAN` |
| 2 | 2 | `GND` |
| 3 | 3 | `+5V_REGULATED` |
| 4 | 4 | `CANFD_A_RXCAN` |
| 5 | 5 | `+3V3` |
| 6 | 6 | `CAN_A_L` |
| 7 | 7 | `CAN_A_H` |
| 8 | 8 | `CANFD_A_XSTBY` |

## U3 - MCP2562FD_CAN_B_3V3_IO
Footprint: `teensy-41-can-lin:SOIC-8_3.9x4.9mm_P1.27mm`

| Pad | Name | Net |
|---|---|---|
| 1 | 1 | `CANFD_B_TXCAN` |
| 2 | 2 | `GND` |
| 3 | 3 | `+5V_REGULATED` |
| 4 | 4 | `CANFD_B_RXCAN` |
| 5 | 5 | `+3V3` |
| 6 | 6 | `CAN_B_L` |
| 7 | 7 | `CAN_B_H` |
| 8 | 8 | `CANFD_B_XSTBY` |

## U4 - TLIN1029DRQ1_LIN_3V3_LOGIC
Footprint: `teensy-41-can-lin:SOIC-8_3.9x4.9mm_P1.27mm`

| Pad | Name | Net |
|---|---|---|
| 1 | 1 | `LIN_RX` |
| 2 | 2 | `LIN_EN` |
| 3 | 3 | `` |
| 4 | 4 | `LIN_TX` |
| 5 | 5 | `GND` |
| 6 | 6 | `LIN_BUS` |
| 7 | 7 | `+12V_PROTECTED` |
| 8 | 8 | `` |

## U5 - LM2596S-5.0_BUCK
Footprint: `teensy-41-can-lin:TO-263-5_TabPin3`

| Pad | Name | Net |
|---|---|---|
|  |  | `` |
|  |  | `` |
|  |  | `` |
|  |  | `` |
| 1 | 1 | `+12V_PROTECTED` |
| 2 | 2 | `BUCK_SW` |
| 3 | 3 | `GND` |
| 3 | 3 | `GND` |
| 4 | 4 | `+5V_REGULATED` |
| 5 | 5 | `GND` |

## U6 - MCP2518FD_A_SOIC14
Footprint: `teensy-41-can-lin:SOIC-14_3.9x8.7mm_P1.27mm`

| Pad | Name | Net |
|---|---|---|
| 1 | 1 | `CANFD_A_TXCAN` |
| 2 | 2 | `CANFD_A_RXCAN` |
| 3 | 3 | `` |
| 4 | 4 | `CANFD_A_INT` |
| 5 | 5 | `CANFD_A_OSC2` |
| 6 | 6 | `CANFD_A_OSC1` |
| 7 | 7 | `GND` |
| 8 | 8 | `` |
| 9 | 9 | `CANFD_A_XSTBY` |
| 10 | 10 | `CANFD_SPI_SCK` |
| 11 | 11 | `CANFD_SPI_SDI_MOSI` |
| 12 | 12 | `CANFD_SPI_SDO_MISO` |
| 13 | 13 | `CANFD_A_NCS` |
| 14 | 14 | `+3V3` |

## U7 - MCP2518FD_B_SOIC14
Footprint: `teensy-41-can-lin:SOIC-14_3.9x8.7mm_P1.27mm`

| Pad | Name | Net |
|---|---|---|
| 1 | 1 | `CANFD_B_TXCAN` |
| 2 | 2 | `CANFD_B_RXCAN` |
| 3 | 3 | `` |
| 4 | 4 | `CANFD_B_INT` |
| 5 | 5 | `CANFD_B_OSC2` |
| 6 | 6 | `CANFD_B_OSC1` |
| 7 | 7 | `GND` |
| 8 | 8 | `` |
| 9 | 9 | `CANFD_B_XSTBY` |
| 10 | 10 | `CANFD_SPI_SCK` |
| 11 | 11 | `CANFD_SPI_SDI_MOSI` |
| 12 | 12 | `CANFD_SPI_SDO_MISO` |
| 13 | 13 | `CANFD_B_NCS` |
| 14 | 14 | `+3V3` |

## Y1 - 40MHz_3225_VERIFY_CL
Footprint: `teensy-41-can-lin:Crystal_SMD_3225-4Pin_3.2x2.5mm_HandSoldering`

| Pad | Name | Net |
|---|---|---|
| 1 | 1 | `CANFD_A_OSC1` |
| 2 | 2 | `GND` |
| 3 | 3 | `CANFD_A_OSC2` |
| 4 | 4 | `GND` |

## Y2 - 40MHz_3225_VERIFY_CL
Footprint: `teensy-41-can-lin:Crystal_SMD_3225-4Pin_3.2x2.5mm_HandSoldering`

| Pad | Name | Net |
|---|---|---|
| 1 | 1 | `CANFD_B_OSC1` |
| 2 | 2 | `GND` |
| 3 | 3 | `CANFD_B_OSC2` |
| 4 | 4 | `GND` |

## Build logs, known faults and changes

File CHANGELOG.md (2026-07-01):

# Changelog

## 2026-07-01 — Latest-tree cleanup and README polish

- Polished the public README for the renamed `obdee-wan-canobi` repository.
- Removed cleanup manifests from the latest branch.
- Removed duplicated R10/R9 revision folders from the latest tree; those snapshots remain available through Git history/releases/tags.
- Kept only the active R11 prototype candidate under `revisions/`.
- Rechecked the active R11 KiCad board with KiCad CLI after cleanup: 0 DRC violations, 1 reviewed GND zone-to-zone residual.

## 2026-06-30 — R10 status correction: NOT FOR FAB

- Reclassified R10 as an inspection/review revision only after external review.
- Confirmed R10 architecture is correct for true dual CAN FD, but not orderable.
- Added `R10_EXTERNAL_REVIEW_FINDINGS_20260630.md` with blockers for R10A/R11.
- Updated README/status files to warn not to send the R10 JLCPCB Gerber ZIP to fabrication.

## R10 true dual CAN FD active release - 2026-06-30

### Status

R10 is now the active cleaned hardware revision for the true dual CAN FD + LIN/K interface.

### Added

- Added cleaned active revision folder: `revisions/00_ACTIVE_R10_TRUE_DUAL_CANFD/`.
- Added canonical R10 KiCad source using MCP2518FD controllers and MCP2562FD transceivers.
- Added regenerated JLCPCB/root-upload Gerber ZIP: `R10_TRUE_DUAL_CANFD_JLCPCB_GERBERS.zip`.
- Added full R10 source/handoff ZIP: `R10_TRUE_DUAL_CANFD_FULL_PACKAGE.zip`.
- Added cleanup/reorganization manifests under `99_MANIFESTS/`.
- Added `README_START_HERE.txt` as the top-level project navigation file.

### Verification

R10 was verified from the cleaned active revision folder with KiCad CLI 10.0.3.

- DRC violations: 0
- Unconnected pads/items: 0
- Footprint errors: 0
- Gerber/drill export: passed

### Changed

- Reorganized the repository around explicit revision folders.
- Archived R9 under `revisions/01_R9_CLASSIC_CAN_ARCHIVE/`.
- Updated root README and current status to point to R10 as the active design.

### Removed from current branch layout

- Removed root-level test/draft/intermediate R10 KiCad files.
- Removed failed optimization artifacts.
- Removed FreeRouting scratch directories.
- Removed intermediate R10 DRC reports superseded by the cleaned-folder DRC recheck.
- Removed obsolete root `hardware/`, `docs/`, and `fabrication/` layout after valid contents were moved into revision folders.

## R10 true dual CAN FD target - 2026-06-29

### Status

The project requirement changed to **true dual CAN FD**. R9 is no longer the final target board; it is now bench-only/classic-CAN prototype material.

### Added

- Added R10 redesign planning documents.
- Added R10 MCP2518FD controller architecture notes.
- Updated R9 BOM/netlist docs so they are PCB-derived and no longer describe stale TJA1051/TJA1020/DB9/USB-C content as current hardware.

### Required for R10

- Add MCP2518FD CAN FD controller x2.
- Keep MCP2562FD transceiver x2.
- Route Teensy SPI + CS/INT/RESET to the controllers.
- Create authoritative schematic and updated BOM before any R10 fab-ready claim.

## Repository cleanup - 2026-06-22

### Changed

- Reorganized the public repository around the then-current R9 FAB_READY release.
- Moved authoritative KiCad source and local footprints to `hardware/kicad/`.
- Moved R9 Gerbers, reports, and release package to `fabrication/r9/`.
- Moved public user-facing hardware docs to `docs/`.

### Removed from current branch

- Removed intermediate R5/R6/R7 KiCad variants, Gerbers, preview SVGs, BOMs, and reports from the public tree.
- Removed all tracked generation scripts from the public repository.
- Removed firmware/code example file from the public repository to keep code/scripts private.

## R9 FAB_READY - 2026-06-22

### Status

R9 was the manufacturing prototype candidate for the Teensy 4.1 dual classic CAN + LIN/K automotive interface using CAN-FD-capable transceivers. After the 2026-06-29 true-FD decision, R9 is no longer the final target board.

### Added

- Added explicit R9 final-candidate KiCad PCB/project files.
- Added clean FAB_READY manufacturing ZIP.
- Added R9 Gerber/drill outputs.
- Added R9 verification reports.
- Added project-local footprint library support.

### Verification

R9 was verified from the cleaned project copy with KiCad CLI 10.0.3.

- DRC violations: 0
- Unconnected pads/items: 0
- Footprint errors: 0
- Gerber/drill export: passed

### Notes

- The legacy schematic is not authoritative for R9. Manufacturing confidence is based on the KiCad PCB source, project-local footprints, KiCad CLI DRC, and KiCad-generated Gerber/drill files.
- R9 remains first-run prototype/reference hardware: order a small batch only if intentionally testing the older classic-CAN architecture, bench-test power rails first, start with passive/read-only firmware, and verify the OBD2 pigtail pinout with a multimeter.

## Earlier intermediate revisions

R5, R6, and R7 were development/intermediate variants leading to R9. They are no longer tracked in the current public branch layout.

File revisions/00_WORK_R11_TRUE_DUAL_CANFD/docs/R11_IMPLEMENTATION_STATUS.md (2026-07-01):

# R11 implementation status

Status: PROTOTYPE_MANUFACTURING_CANDIDATE for small bare-PCB bench bring-up batch.
Vehicle status: NOT VEHICLE-READY.

## Active source

- `../kicad/teensy-41-true-dual-canfd-lin-r11_JARVIS_ROUTED_CLEAN_V2_GND_STITCH.kicad_pcb`
- `../kicad/teensy-41-true-dual-canfd-lin-r11_JARVIS_ROUTED_CLEAN_V2_GND_STITCH.kicad_pro`

## Release package

- `../release/R11_PROTOTYPE_MANUFACTURING_CANDIDATE_20260630/`

Use this manufacturer upload ZIP:

- `../release/R11_PROTOTYPE_MANUFACTURING_CANDIDATE_20260630/package/JLCPCB_PCBWAY_UPLOAD_R11_MINIMAL_GERBERS_ONLY_20260630.zip`

## KiCad verification

Reports:

- `../release/R11_PROTOTYPE_MANUFACTURING_CANDIDATE_20260630/reports/R11_PROTOTYPE_CANDIDATE_DRC.rpt`
- `../release/R11_PROTOTYPE_MANUFACTURING_CANDIDATE_20260630/reports/R11_PROTOTYPE_CANDIDATE_CLEAN_RELEASE_COPY_DRC.rpt`

Result:

- DRC violations: 0
- Footprint errors: 0
- Known residual: one GND zone-to-zone unconnected report at 1.0000 mm / 1.0000 mm
- GND continuity: visually confirmed in KiCad after zone refill/highlight
- Gerbers/drill: exported successfully by KiCad CLI

## Schematic, ERC, and BOM

Added from the active PCB on 2026-07-01:

- `../kicad/teensy-41-true-dual-canfd-lin-r11_JARVIS_ROUTED_CLEAN_V2_GND_STITCH.kicad_sch`
- `R11_BOM_FROM_PCB.md` / `.csv`
- `R11_BOM_GROUPED_FROM_PCB.csv`
- `R11_JLCPCB_BOM_DRAFT.csv`
- `R11_JLCPCB_CPL_DRAFT.csv`
- `R11_PCB_DERIVED_NETLIST.md`
- `R11_PAD_NETS_FROM_PCB.csv`
- `R11_KICAD_PYTHON_BOM.xml`

KiCad schematic ERC result: 0 errors / 0 warnings.

Limitation: the schematic is PCB-derived and footprint-linked for BOM/ERC hygiene. It is not yet a hand-reviewed, fully wired functional schematic. The PCB and pad/net export remain the electrical authority for review.

## Safety status

Acceptable next step:

- Order a small bare-PCB prototype batch for bench bring-up.

Not acceptable yet:

- Do not order assembly.
- Do not connect to a vehicle.
- Do not call this final/fab-ready for general use.

Before vehicle testing, verify bare board continuity, power rails, OBD/pigtail pin mapping, DIP switch defaults, CAN/LIN/K behavior on bench hardware, and fused OBD connection procedure.

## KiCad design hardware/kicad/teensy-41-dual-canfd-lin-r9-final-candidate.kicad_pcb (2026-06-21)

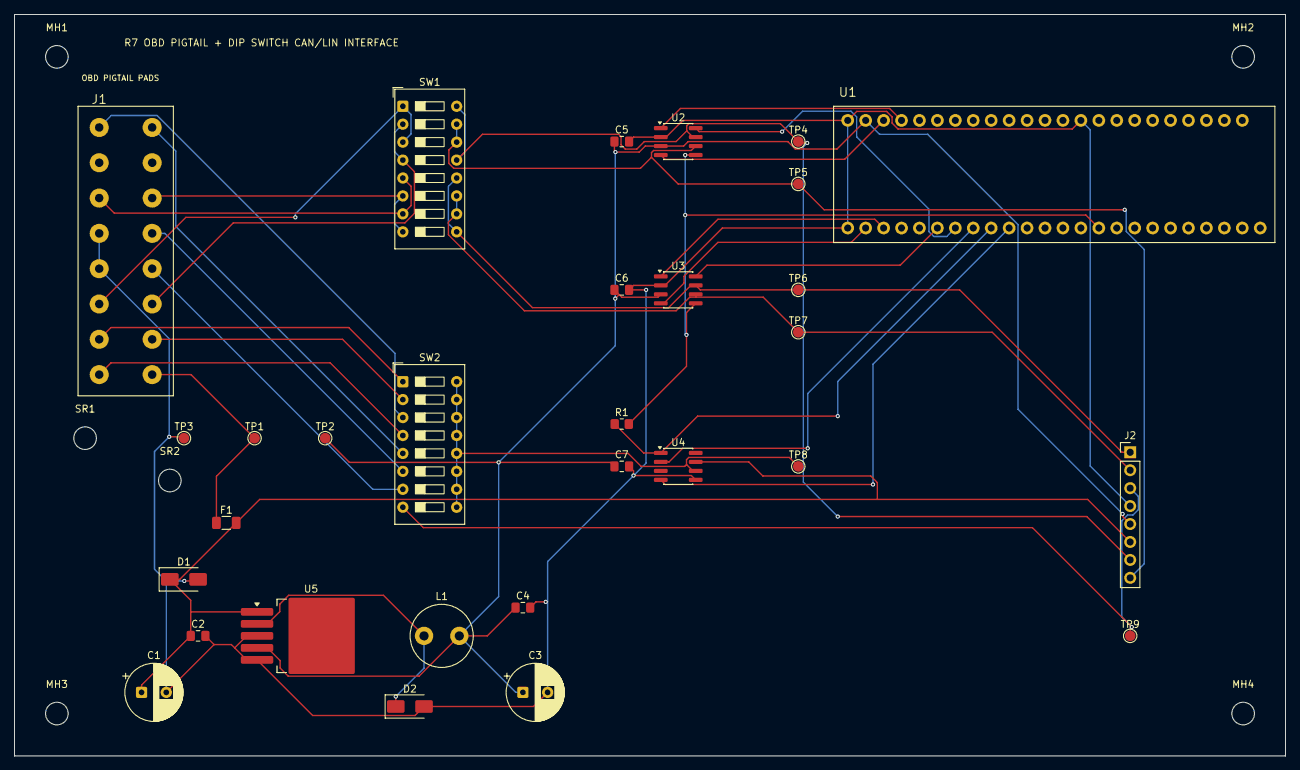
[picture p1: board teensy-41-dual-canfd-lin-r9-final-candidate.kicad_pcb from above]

Board: 2 copper layers, 180.0 x 105.0 mm, 36 parts (0 on the bottom side), 32 nets.

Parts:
C1: 100uF_50V_INPUT; CP_Radial_D8.0mm_P3.50mm
C2: 100nF_50V_INPUT; C_0805_2012Metric_Pad1.18x1.45mm_HandSolder
C3: 330uF_16V_OUTPUT_LOW_ESR; CP_Radial_D8.0mm_P3.50mm
C4: 100nF_16V_OUTPUT; C_0805_2012Metric_Pad1.18x1.45mm_HandSolder
C5: 100nF_CAN_A_DECOUPLING; C_0805_2012Metric_Pad1.18x1.45mm_HandSolder
C6: 100nF_CAN_B_DECOUPLING; C_0805_2012Metric_Pad1.18x1.45mm_HandSolder
C7: 100nF_LIN_DECOUPLING; C_0805_2012Metric_Pad1.18x1.45mm_HandSolder
D1: SMBJ24CA_TVS_12V; D_SMA
D2: SS34_BUCK_SCHOTTKY; D_SMA
F1: POLYFUSE_500mA; Fuse_1206_3216Metric
J1: OBD2_PIGTAIL_16_WIRE_SOLDER_PADS; OBD2_PigtailPads_Manufacturing
J2: AUX_HEADER; PinHeader_1x08_P2.54mm_Vertical
L1: 33uH_3A_BUCK_INDUCTOR; L_Radial_D8.7mm_P5.00mm_Fastron_07HCP
MH1, MH2, MH3, MH4: M3; MountingHole_3.2mm_M3
R1: 10k_LIN_RX_PULLUP; R_0805_2012Metric_Pad1.20x1.40mm_HandSolder
SR1, SR2: CABLE_STRAIN_RELIEF; MountingHole_3.2mm_M3
SW1: CAN_NORMAL_CROSS_DIP_8POS; SW_DIP_SPSTx08_Slide_9.78x22.5mm_W7.62mm_P2.54mm
SW2: LIN_K_SOURCE_DIP_8POS_SELECT_ONE; SW_DIP_SPSTx08_Slide_9.78x22.5mm_W7.62mm_P2.54mm
TP1: 12V; TestPoint_Pad_D1.5mm
TP2: 5V; TestPoint_Pad_D1.5mm
TP3: GND; TestPoint_Pad_D1.5mm
TP4: CAN_A_H; TestPoint_Pad_D1.5mm
TP5: CAN_A_L; TestPoint_Pad_D1.5mm
TP6: CAN_B_H; TestPoint_Pad_D1.5mm
TP7: CAN_B_L; TestPoint_Pad_D1.5mm
TP8: LIN_BUS; TestPoint_Pad_D1.5mm
TP9: AUX_LIN_K; TestPoint_Pad_D1.5mm
U1: TEENSY_4.1_MAIN_HEADERS_PJRC_AUDITED; Teensy_4.1_MainHeaders_PJRC_Audited
U2: MCP2562FD_CAN_A_3V3_IO; SOIC-8_3.9x4.9mm_P1.27mm
U3: MCP2562FD_CAN_B_3V3_IO; SOIC-8_3.9x4.9mm_P1.27mm
U4: TLIN1029DRQ1_LIN_3V3_LOGIC; SOIC-8_3.9x4.9mm_P1.27mm
U5: LM2596S-5.0_BUCK; TO-263-5_TabPin3

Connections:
+3V3: R1.2, U1.3V3_B, U2.5, U3.5
+5V_REGULATED: C3.1, C4.1, C5.1, C6.1, C7.1, J2.5, L1.2, TP2.1, U1.VIN, U2.3, U3.3, U5.4
+12V_OBD: F1.1, J1.16, TP1.1
+12V_PROTECTED: C1.1, C2.1, D1.1, F1.2, J2.6, U4.7, U5.1
AUX_LIN_K_IO: J2.3, SW2.8, TP9.1
BUCK_SW: D2.1, L1.1, U5.2
CAN_A_H: J2.7, SW1.13, SW1.16, TP4.1, U2.7
CAN_A_L: J2.8, SW1.14, SW1.15, TP5.1, U2.6
CAN_A_RX: U1.23, U2.4
CAN_A_STB: U1.5, U2.8
CAN_A_TX: U1.22, U2.1
CAN_B_H: J2.1, SW1.9, SW1.12, TP6.1, U3.7
CAN_B_L: J2.2, SW1.10, SW1.11, TP7.1, U3.6
CAN_B_RX: U1.0, U3.4
CAN_B_STB: U1.4, U3.8
CAN_B_TX: U1.1, U3.1
GND: C1.2, C2.2, C3.2, C4.2, C5.2, C6.2, C7.2, D1.2, D2.2, J1.4, J1.5, J2.4, TP3.1, U1.GND_B1, U1.GND_T1, U1.GND_T2, U2.2, U3.2, U4.5, U5.3, U5.5
LIN_BUS: SW2.9, SW2.10, SW2.11, SW2.12, SW2.13, SW2.14, SW2.15, SW2.16, TP8.1, U4.6
LIN_EN: U1.6, U4.2
LIN_RX: R1.1, U1.7, U4.1
LIN_TX: U1.8, U4.4
OBD1_SINGLE_WIRE_CANDIDATE: J1.1, SW2.3
OBD3_CAN_B_PAIR_A_CANDIDATE: J1.3, SW1.5, SW1.7
OBD6_CAN_A_PAIR_A: J1.6, SW1.1, SW1.3
OBD7_SINGLE_WIRE_CANDIDATE: J1.7, SW2.1
OBD8_SINGLE_WIRE_CANDIDATE: J1.8, SW2.4
OBD9_SINGLE_WIRE_CANDIDATE: J1.9, SW2.5
OBD11_CAN_B_PAIR_B_CANDIDATE: J1.11, SW1.6, SW1.8
OBD12_SINGLE_WIRE_CANDIDATE: J1.12, SW2.6
OBD13_SINGLE_WIRE_CANDIDATE: J1.13, SW2.7
OBD14_CAN_A_PAIR_B: J1.14, SW1.2, SW1.4
OBD15_SINGLE_WIRE_CANDIDATE: J1.15, SW2.2

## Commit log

2026-06-21 Add R7 Teensy footprint corrected candidate
    [BOM_R7_PROCUREMENT_EU.csv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]
2026-06-22 Add R9 FAB_READY hardware release
    Promote R9 as the active manufacturing prototype candidate. Include KiCad PCB source, project-local footprints, Gerber/drill outputs, DRC reports, clean FAB_READY package, and changelog.
    [teensy-41-dual-canfd-lin-r9-final-candidate-B_Cu.gbl, teensy-41-dual-canfd-lin-r9-final-candidate-B_Mask.gbs, teensy-41-dual-canfd-lin-r9-final-candidate-B_Sil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]
2026-06-22 Organize public R9 hardware release
    [BOM_R5_PIGTAIL_DIPSWITCH.csv, BOM_R6_PROCUREMENT_EU.csv, BOM_R7_PROCUREMENT_EU.csv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]
2026-06-30 Add R10 true dual CAN FD release
    [R10_TRUE_DUAL_CANFD-pcb-bom.csv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]
2026-07-01 Clean latest repository tree
    [R10_TRUE_DUAL_CANFD-pcb-bom.csv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]
2026-07-01 Add R11 PCB-derived schematic and BOM outputs
    [R11_BOM_FROM_PCB.csv, R11_BOM_GROUPED_FROM_PCB.csv, R11_JLCPCB_BOM_DRAFT.csv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]
